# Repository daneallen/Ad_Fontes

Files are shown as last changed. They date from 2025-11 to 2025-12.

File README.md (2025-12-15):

# Ad Fontes STEM Project 2025

A project intended to introduce students to electrical engineering, printed circuit
board (PCB) design, soldering and embedded microcontroller programming.

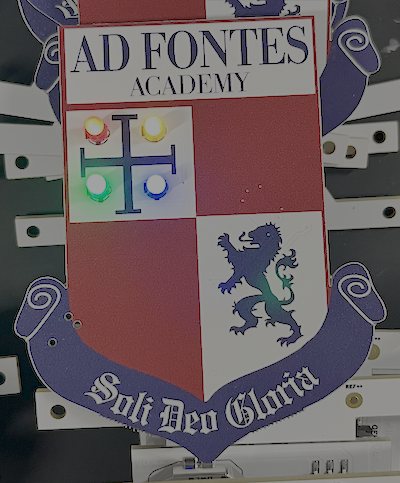
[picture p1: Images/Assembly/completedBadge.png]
Ad Fontes Completed Badge


# Day 1

Introduction to circuit design of the project. The entire design of the PCB was
completed using [KiCad](https://www.kicad.org/), a free and open sourced PCB software application.

The design of the circuit is built around the small and very capable [ATtiny1616](https://ww1.microchip.com/downloads/en/DeviceDoc/ATtiny1614-16-17-DataSheet-DS40002204A.pdf) microcontroller.

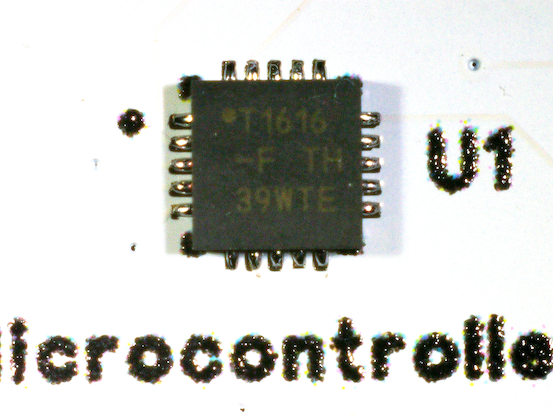
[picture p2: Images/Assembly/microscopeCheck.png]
Close up image of a soldered ATtiny1616


The entire schematic of the PCB is [here](/Documents/Schematic.pdf)

## Design Timeline

| Date | Notes |
| --- | --- |
| 8/23/25 | The PCB was first designed in KiCad |
| 8/28/25 | The first order of PCBs was placed. |
| 9/15/25 | The first of PCBs arrives. The design was sound, however the logo was too dark and there was improvements that could be made |
| 9/19/25 | Order #2 (v02) was placed to fix some of the identified issues |
| 10/6/25 | v02 badges arrive, Overall good, would benefit from a few additional things printed on the back of the board. |
| 10/19/25 | Order #3 (v03) was placed |
| 10/30/25 | v03 badge arrives. There is a problem with the back grounding plane... it was NOT filled in and so nothing works. |
| 11/10/25 | Order #4 (v04) was placed to finally fix all the things. |
| 11/20/25 | v04 arrives and is functional and ready for class. |

### Ideas for improvement

   - [x] lighten the colors for on the front of the badge for more contrast
   - [x] enlarge the test on the back of the badge... possibly expand/point out the different components
   - [x] remove the svg2mod on the front silkscreen
   - [x] better align the image on the front of the badge
   - [x] fix/address/remove the white parts near the mouse bites
   - [x] add a box and label for initials

# Day 2

On this day students will select the 4 LEDs that will be soldered onto their PCB.

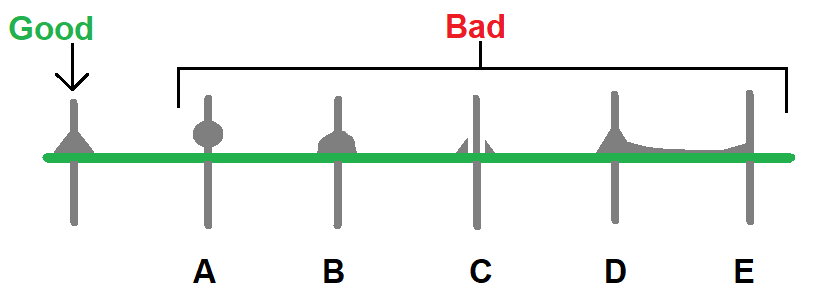
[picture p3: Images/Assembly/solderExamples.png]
Good & Bad solder examples


Basic Steps for Soldering:
   1. Introduce Heat
   2. Introduce Solder
   3. Remove the Solder
   4. Remove the Heat  

[YouTube Link for Soldering Example](https://www.youtube.com/watch?v=eHu_fGAyNY4)

# Day 3

Time to finish the PCB with some custom firmware. The ATtiny1616 utilizes the [Unified Program and Debug Interface (UPDI)]([https://learn.adafruit.com/adafruit-updi-friend/overview) protocol to program the microcontroller. Having the [Adafruit UPDI Friend Programmer](https://www.adafruit.com/product/5879) is quite helpful, especially when using it with the Tag-Connect [TC2030-IDC-NL](https://www.tag-connect.com/product/tc2030-idc-nl) 6-pin plug-of-nails connector tool.

## Programming the Badge

Programming the board is accomplished by using the interactive [programming script](/Arduino/Programming/programming.sh).

Available options are for the board to boot up into one of the following options:
1. Steady On all LEDs
2. Twinkle Effect
3. Chase Effect
4. Breathing Effect

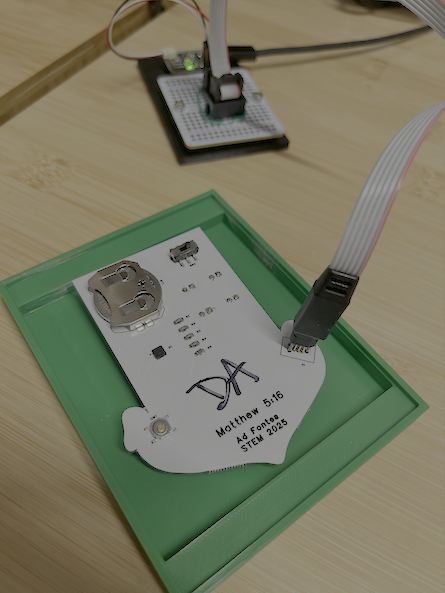
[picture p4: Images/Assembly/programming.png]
Programming the board


## Source Code

[Source Code](/Arduino/adFontes) for the board.

## Behind the Scenes

You will notice that there numerous components already assembled on the board prior to the 4 LEDs. Those components were assembled
in the following manner.

1. Setup the PCB in a jig to apply the solder paste.
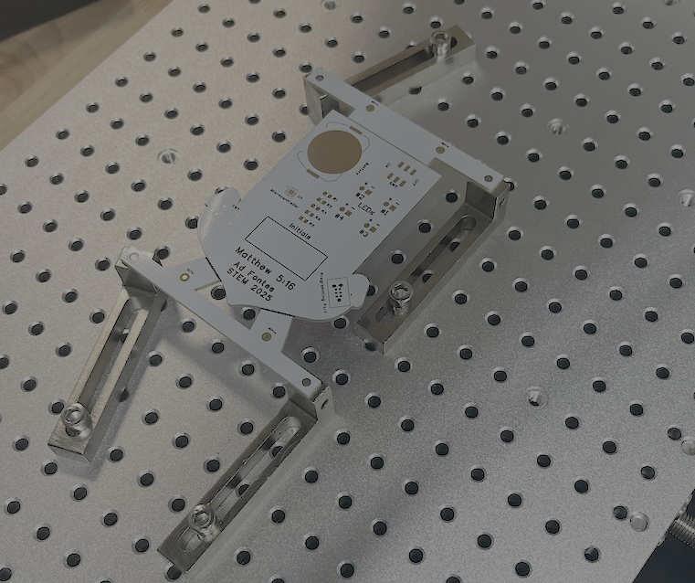
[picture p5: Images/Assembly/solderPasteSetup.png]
Solder Paste Setup


2. Apply the solder paste to the PCB.
Applying the Solder Paste

3. Setup the Pick and Place Machine and have it place all the small components to the board.
[Watch the PnP magic](/Images/Assembly/PnP.mp4)

4. Add the larger components by hand.
<br>Hand Placement of larger components

5. Put the board in the oven.
Placing the boards in the oven

6. Wait about 6 minutes for a freshly cooked badge to come out completed on the other side.
[Cooked badge](/Images/Assembly/ovenFinished.mov)

7. Pick your favorite 4 LED colors, solder them on and enjoy.

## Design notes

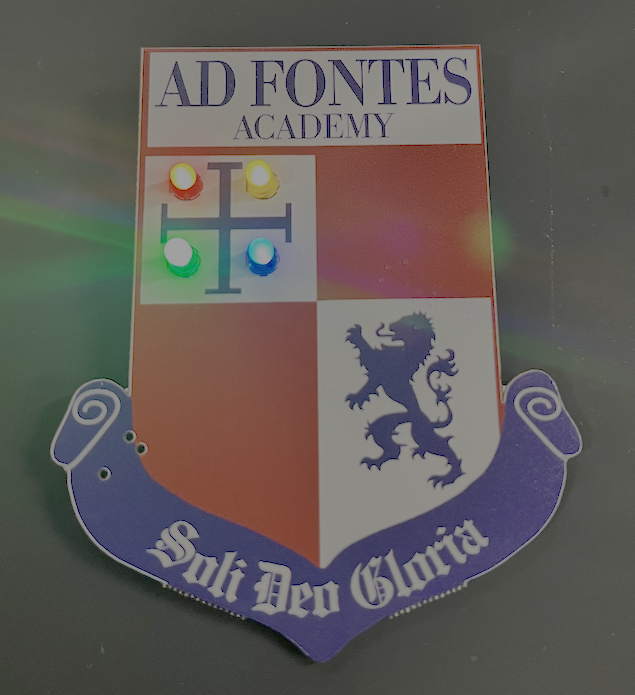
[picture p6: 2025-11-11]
Images/adFontes_front.png

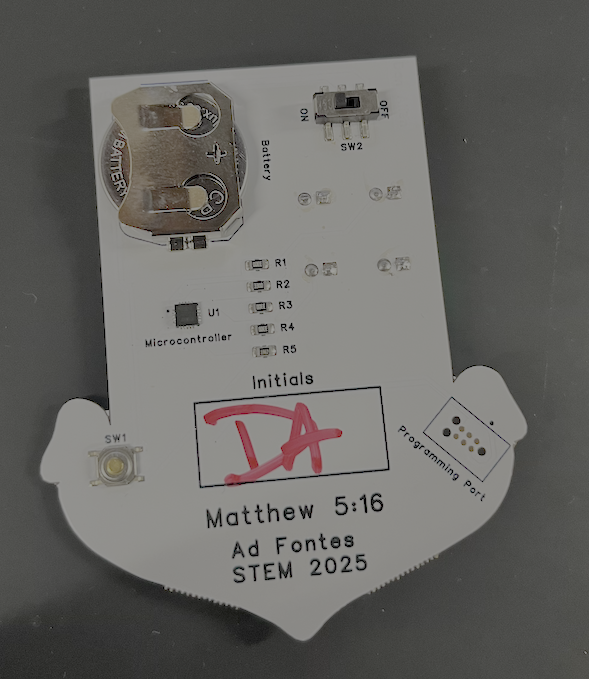
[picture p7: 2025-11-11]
Images/adFontes_back.png

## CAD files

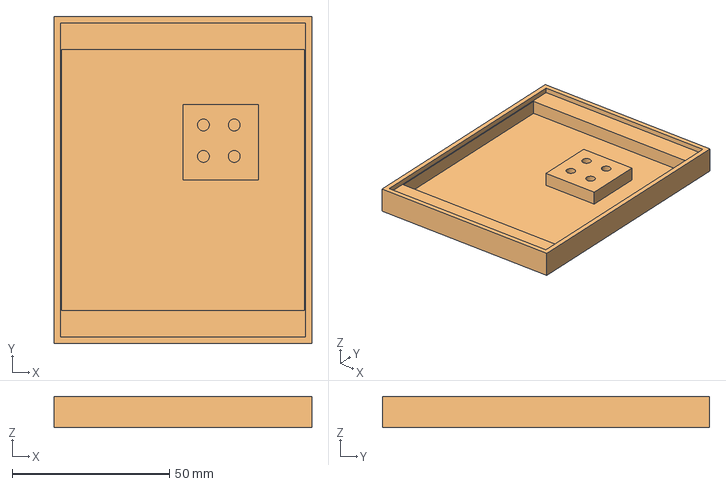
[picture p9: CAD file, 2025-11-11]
Assembly/sodlerJig.FCStd
82.0 x 104.0 x 10.0 mm
solderJig
solderJig (Meshed)

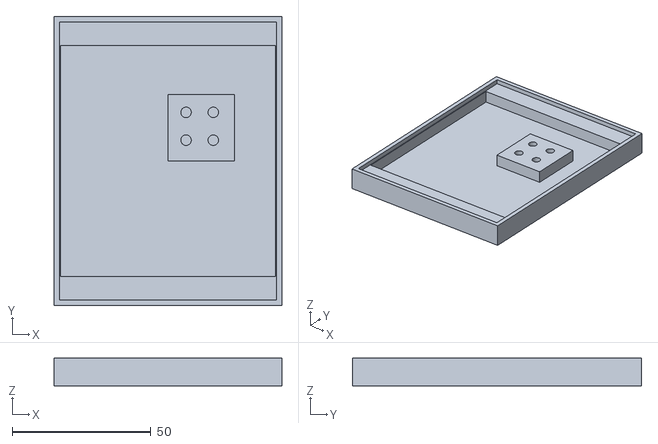
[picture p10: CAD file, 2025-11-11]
Assembly/solderJig (Meshed).stl
82.0 x 104.0 x 10.0

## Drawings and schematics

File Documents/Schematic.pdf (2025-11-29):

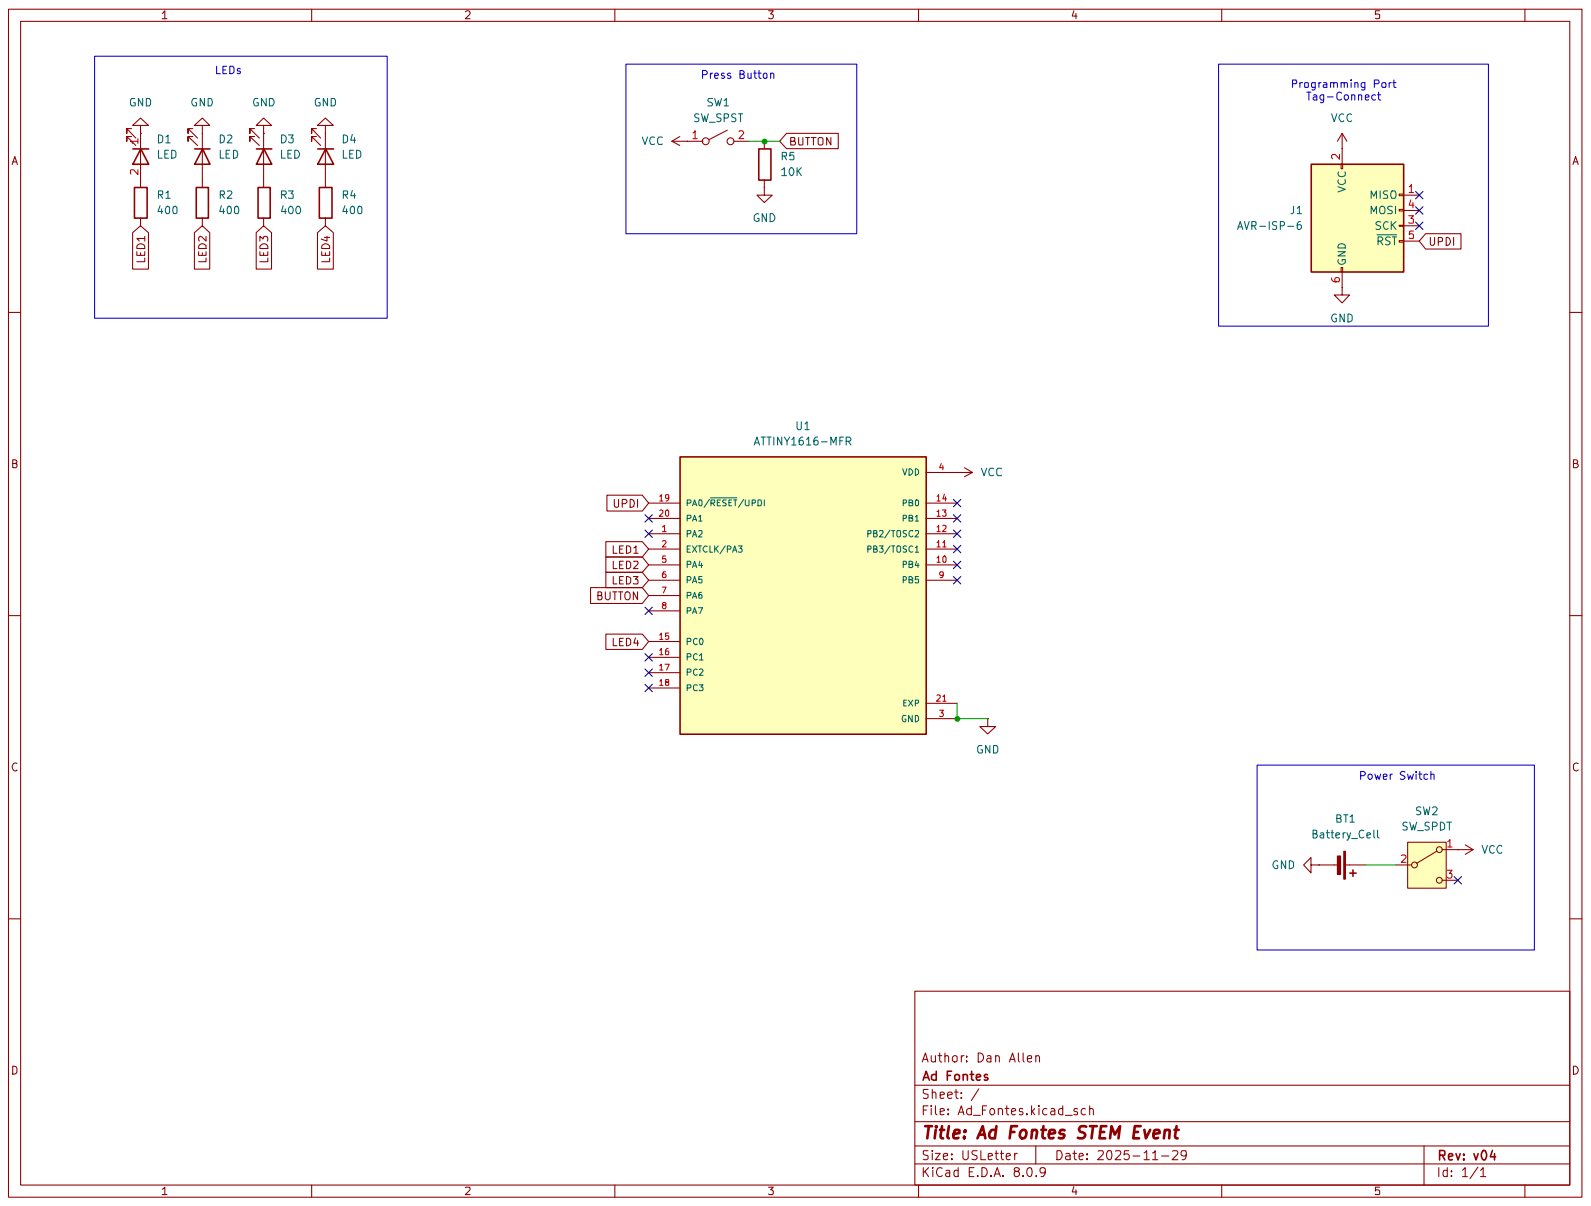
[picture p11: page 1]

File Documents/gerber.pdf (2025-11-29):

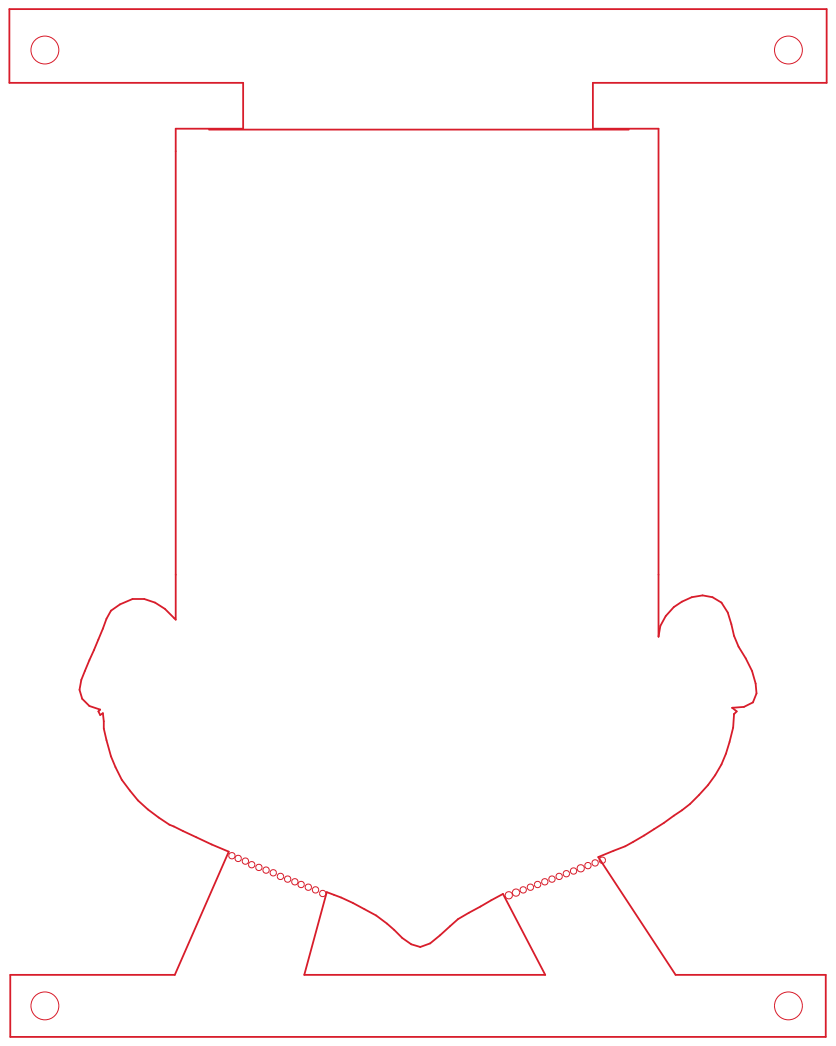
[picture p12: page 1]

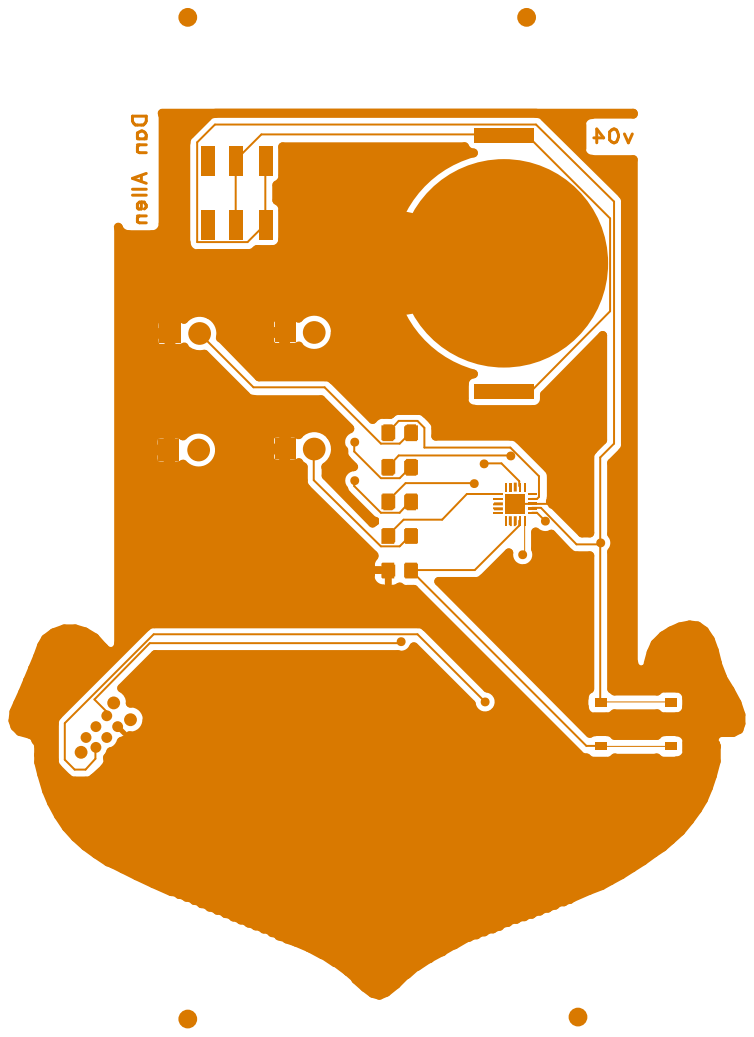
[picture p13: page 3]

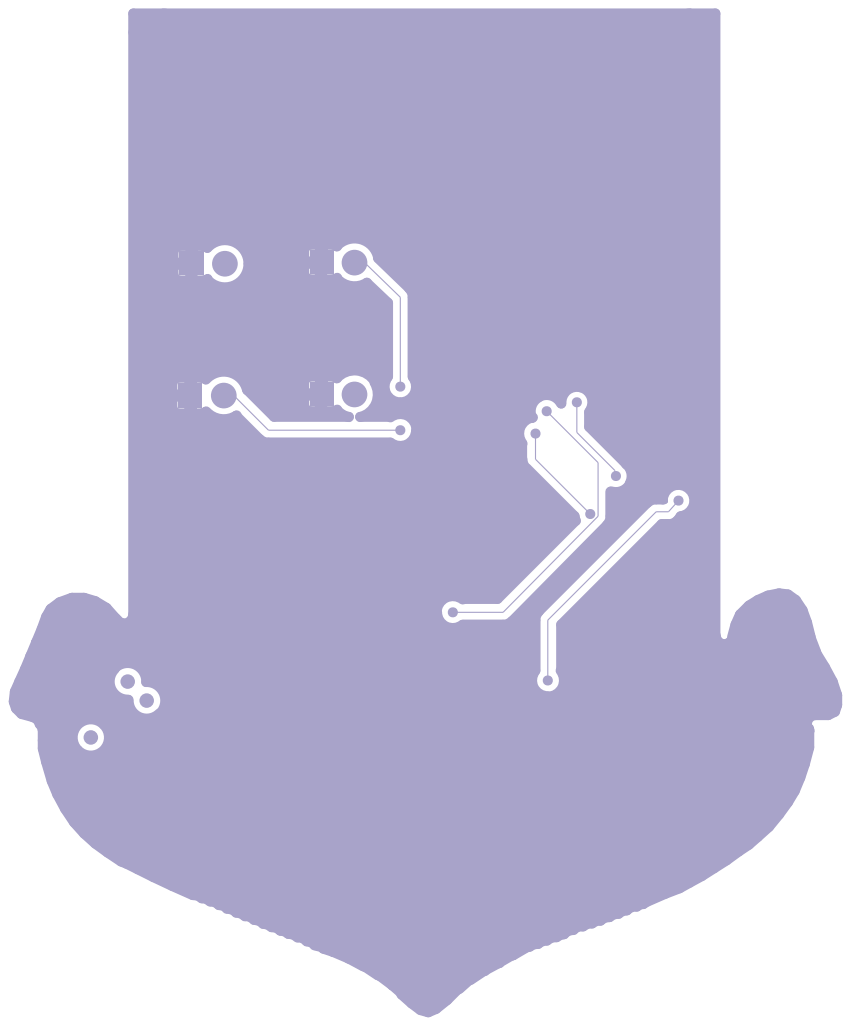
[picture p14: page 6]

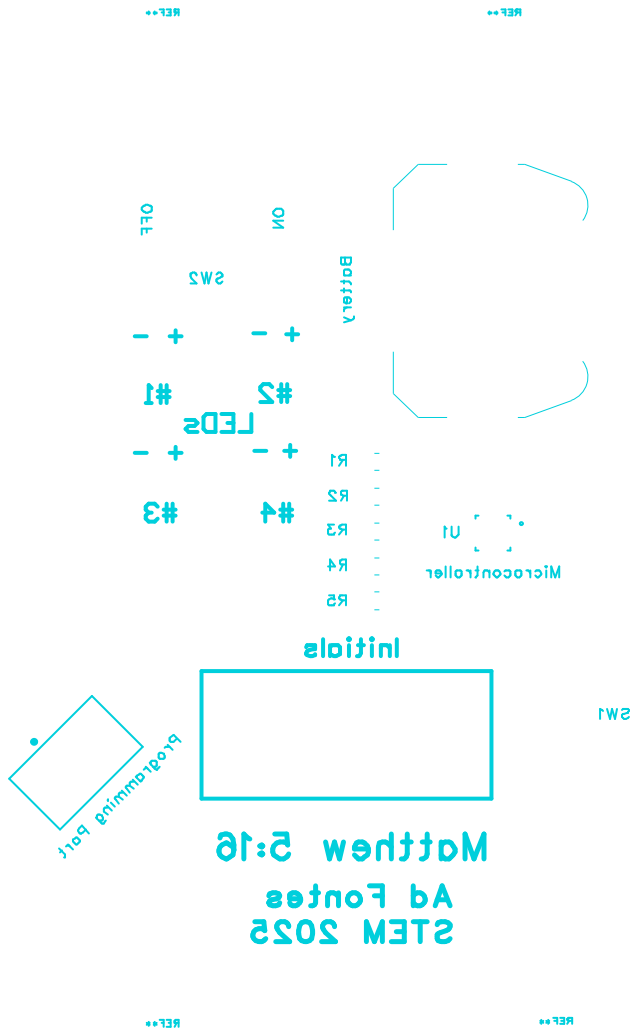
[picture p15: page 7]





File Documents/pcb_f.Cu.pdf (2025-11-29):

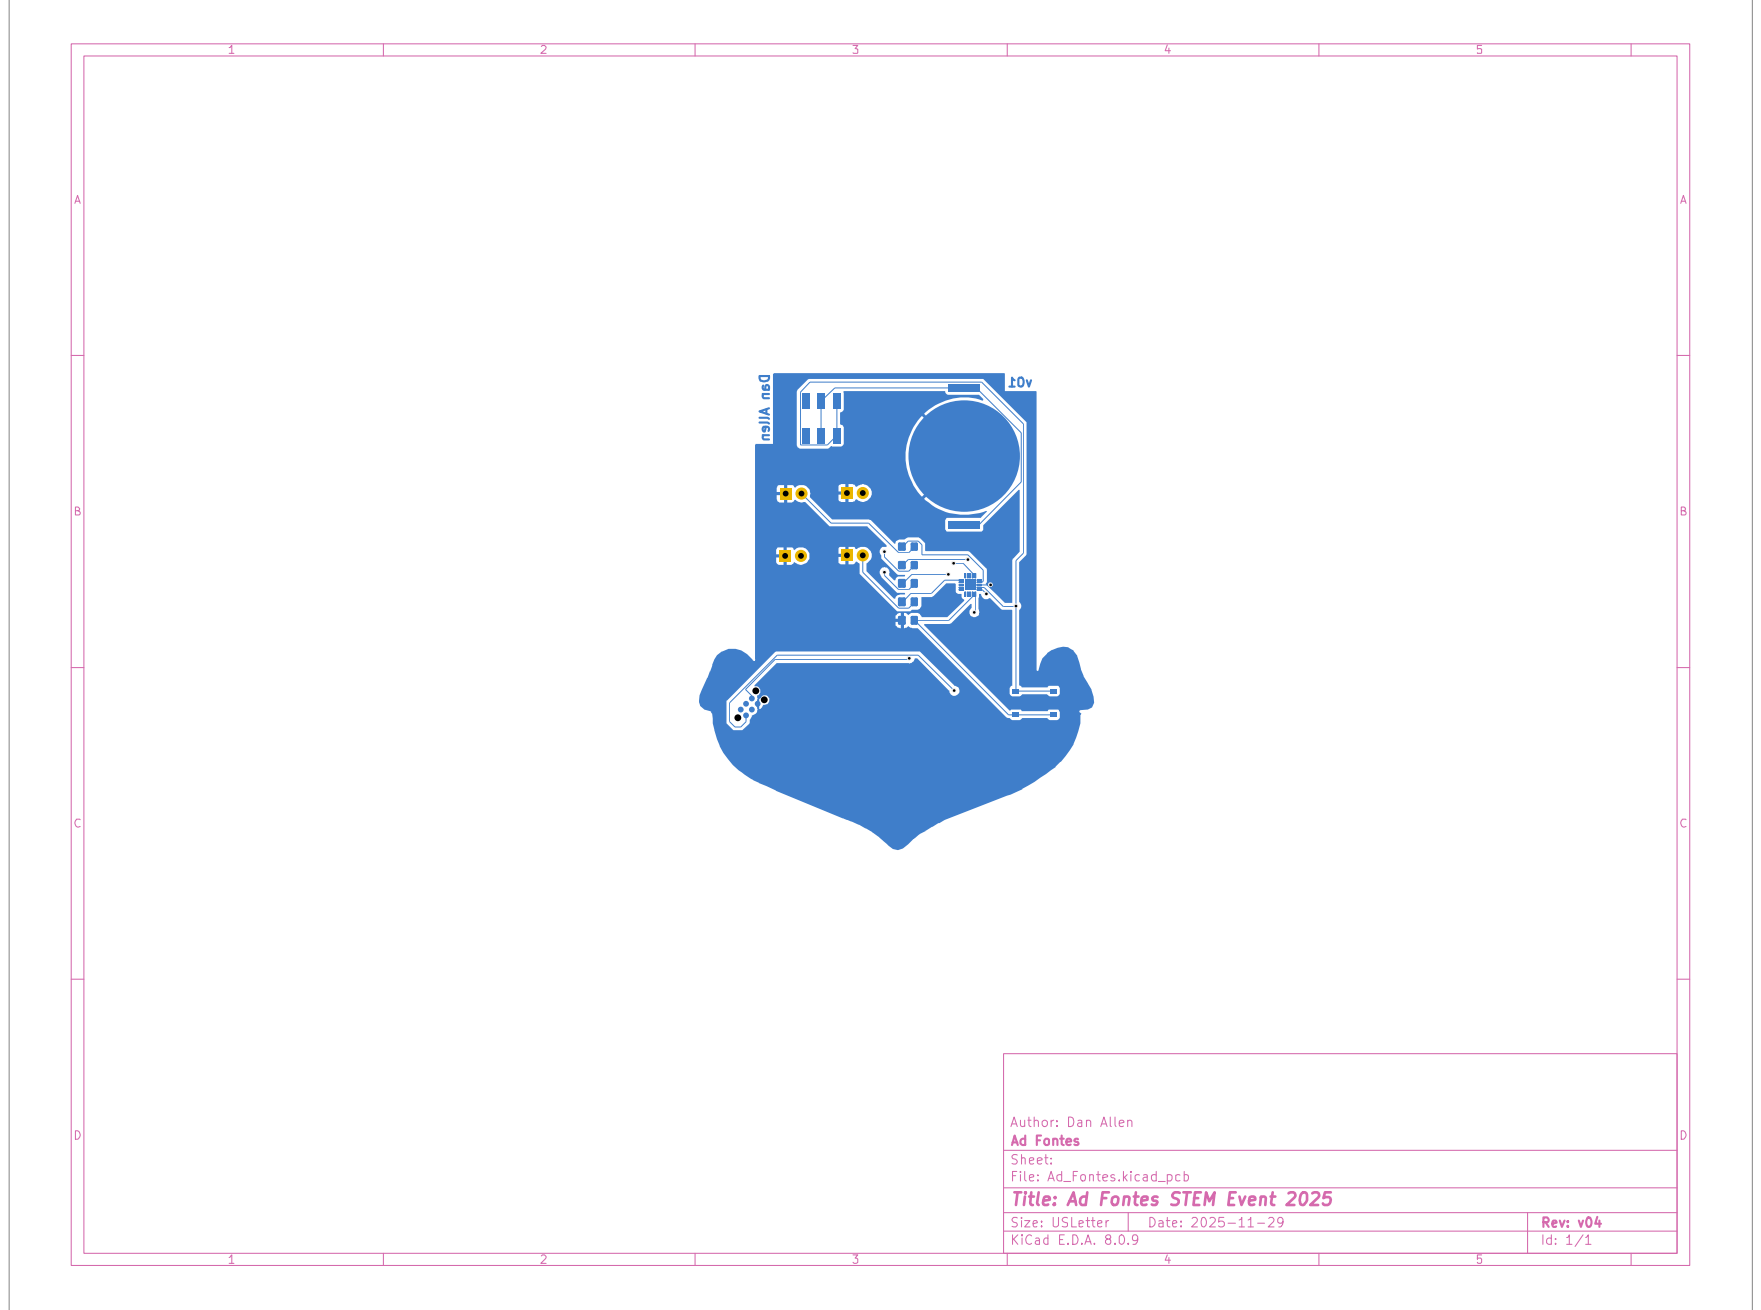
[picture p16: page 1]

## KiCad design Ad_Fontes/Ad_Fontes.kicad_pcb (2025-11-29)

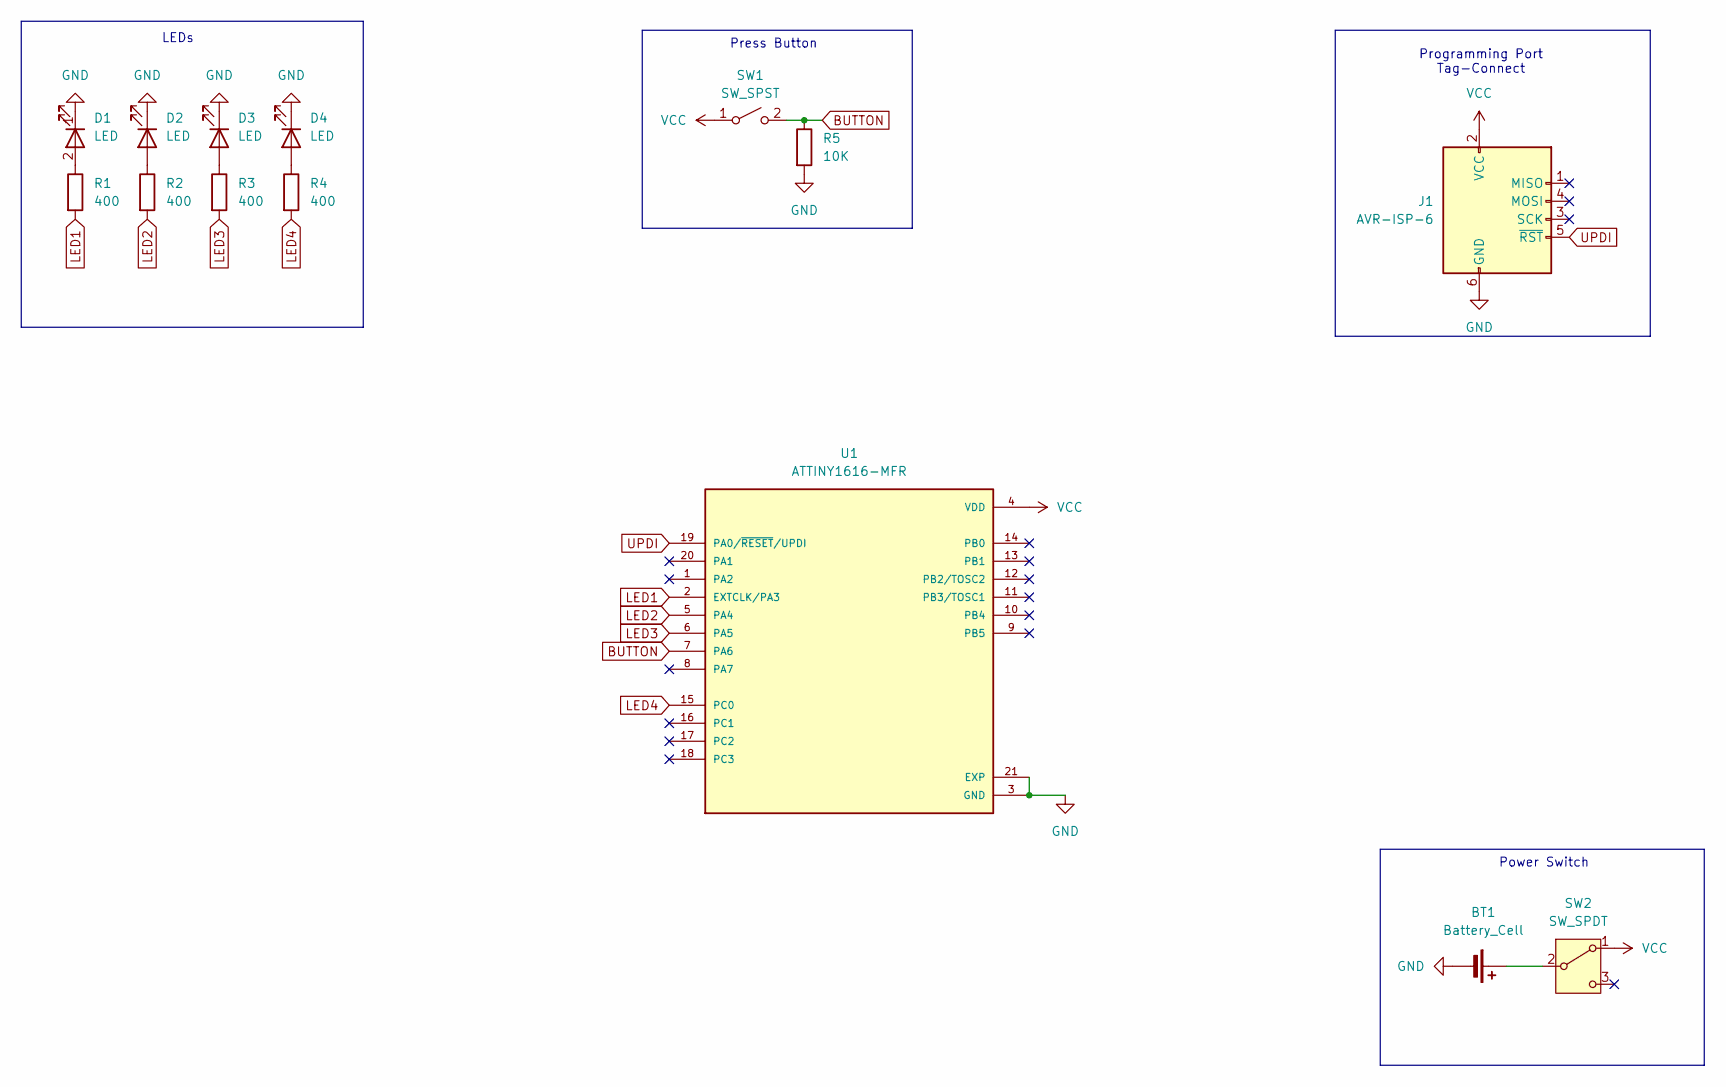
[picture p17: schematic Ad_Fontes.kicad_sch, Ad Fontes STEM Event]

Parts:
BT1: Battery_Cell; BatteryHolder_Keystone_3034_1x20mm
D1, D2, D3, D4: LED; LED_D3.0mm
J1: AVR-ISP-6; TAG_TC2030-IDC-NL
R1, R2, R3, R4: 400; R_0805_2012Metric_Pad1.20x1.40mm_HandSolder
R5: 10K; R_0805_2012Metric_Pad1.20x1.40mm_HandSolder
SW1: SW_SPST; PTS526
SW2: SW_SPDT; switch_JS202011SCQN
U1: ATTINY1616-MFR; QFN40P300X300X90-21N; PARTREV A; DigiKey_Part_Number ATTINY1616-MFRTR-ND

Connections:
BUTTON: R5.1, SW1.2 (B), U1.7 (PA6)
GND: BT1.2 (-), D1.1 (K), D2.1 (K), D3.1 (K), D4.1 (K), J1.6 (GND), R5.2, U1.3 (GND), U1.21 (EXP)
LED1: R1.2, U1.2 (EXTCLK/PA3)
LED2: R2.2, U1.5 (PA4)
LED3: R3.2, U1.6 (PA5)
LED4: R4.2, U1.15 (PC0)
unnamed: BT1.1 (+), SW2.2 (B)
unnamed: D1.2 (A), R1.1
unnamed: D2.2 (A), R2.1
unnamed: D3.2 (A), R3.1
unnamed: D4.2 (A), R4.1
UPDI: J1.5 (~RST), U1.19 (PA0/~RESET/UPDI)
VCC: J1.2 (VCC), SW1.1 (A), SW2.1 (A), U1.4 (VDD)

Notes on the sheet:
Press Button
LEDs
Programming Port Tag-Connect
Power Switch

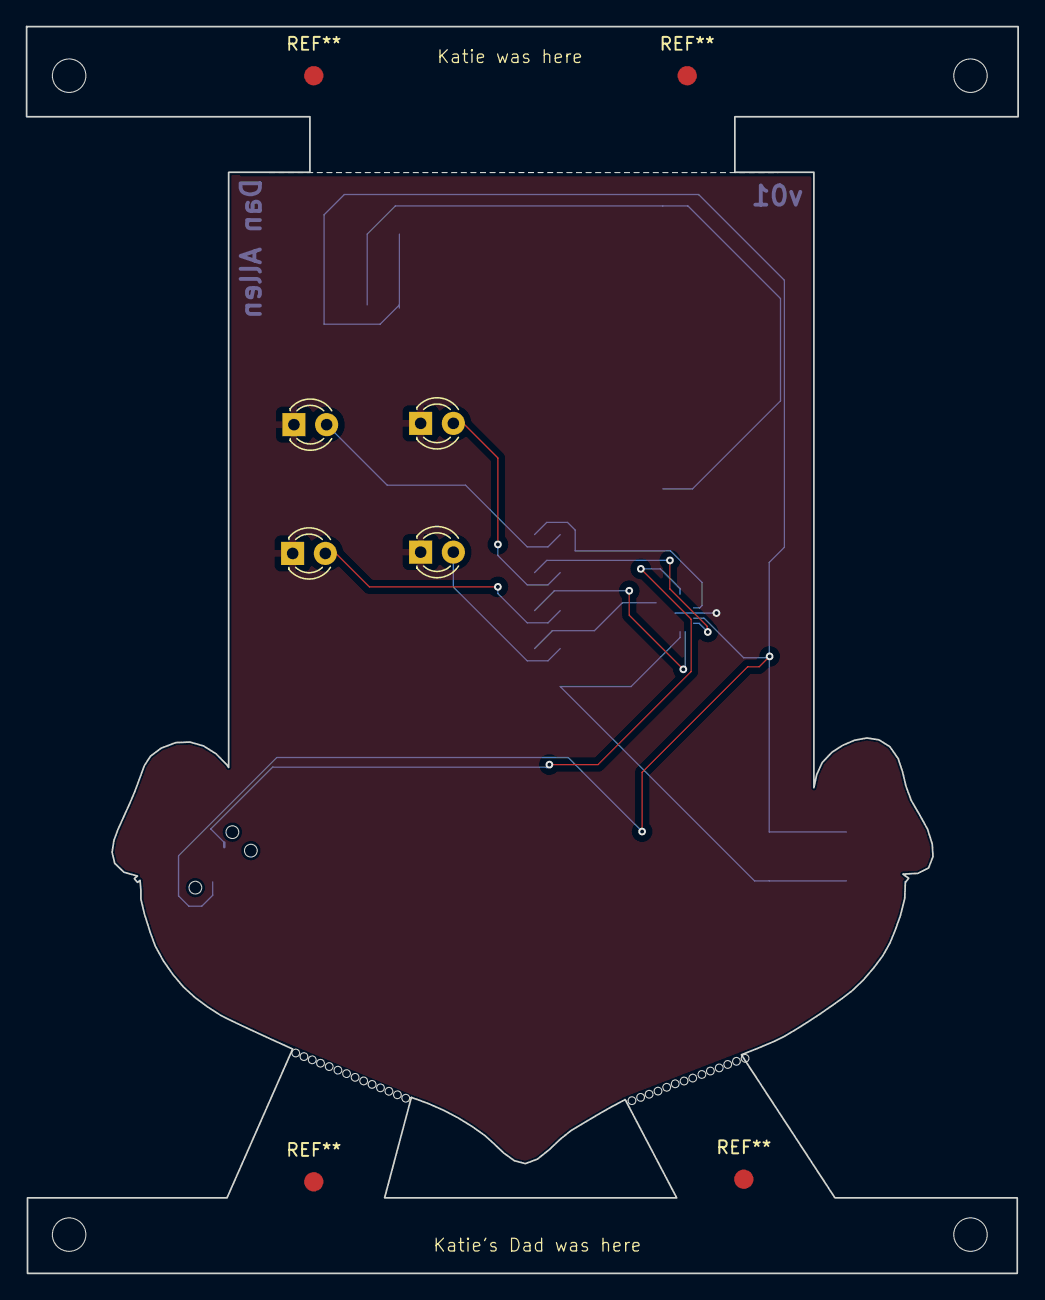
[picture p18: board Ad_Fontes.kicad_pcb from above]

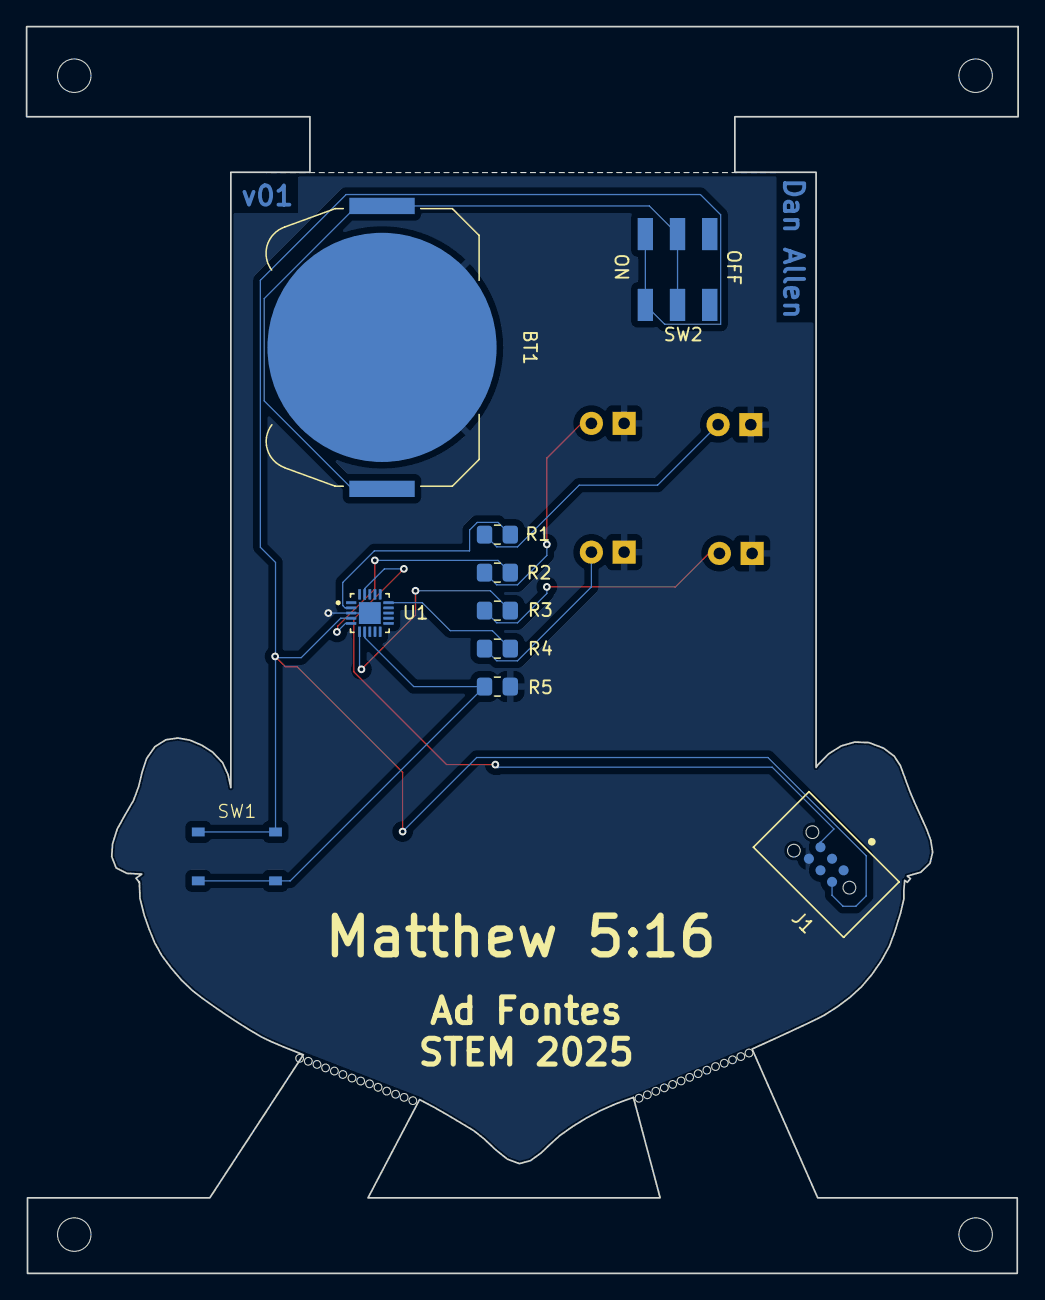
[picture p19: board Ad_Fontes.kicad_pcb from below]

Board: 2 copper layers, 77.0 x 96.8 mm, 15 parts (10 on the bottom side), 13 nets.

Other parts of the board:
svg2mod: G***; Ad Fontes Crest Logo

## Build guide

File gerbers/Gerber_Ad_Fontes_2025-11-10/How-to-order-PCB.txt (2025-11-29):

How to Order PCB

Please refer to:
https://prodocs.easyeda.com/en/pcb/order-order-pcb/index.html

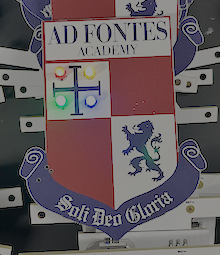
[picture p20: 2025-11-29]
Images/Assembly/completedFunctional.png

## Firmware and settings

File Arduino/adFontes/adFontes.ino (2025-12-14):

/* Ad Fontes STEM Badge 2025
 * 
 * author: @cybertestpilot
 * 
 */

#include <SoftwareTimer.h>

// The definitions of the pins mapped to the MCU
#define LED1 PIN_PA3
#define LED2 PIN_PA4
#define LED3 PIN_PA5
#define LED4 PIN_PC0
#define BUTTON A6


int led_array[4] = {LED1, LED2, LED3, LED4};
int led_array_index = 0;

int buttonState;            // the current reading from the input pin
int lastButtonState = LOW;  // the previous reading from the input pin

unsigned long lastDebounceTime = 0;  // the last time the output pin was toggled
unsigned long debounceDelay = 50;

// The initial value the board is set to for the purposes of the the LED initial state
int LED_STATE = 9;

int delay_value = 0;

// The delay value being used to set the twinkle effect of the random blinking
bool doTwinkle = false;
bool doDelay = false; 
unsigned long delayStart = 0;
unsigned long delayLenFast = 100;

void twinkleEffect();
SoftwareTimer twinkleTimer(100, &twinkleEffect);

void chaseEffect();
SoftwareTimer chaseTimer(200, &chaseEffect);
bool doChase = false;
int chaseIndex = 0;
int led_chase_array[4] = {LED1, LED2, LED4, LED3};

void breatheEffect();
SoftwareTimer breathTimer(15, &breatheEffect);
bool doBreathe = false;
int breathValue = 1;
int breathDir = 1;


void setup() {
  
  // put your setup code here, to run once:
  pinMode(LED1, OUTPUT);
  pinMode(LED2, OUTPUT);
  pinMode(LED3, OUTPUT);
  pinMode(LED4, OUTPUT);
  
  pinMode(BUTTON, INPUT);  
}

void twinkleEffect(){
  if(doTwinkle == true){
    for(int i=0; i<4; i++){
      analogWrite(led_array[i], random(1,255));
    }
  }
}

void chaseEffect(){
  if(doChase == true){
    for(int i=0; i<4; i++){
      if(i == chaseIndex){
        digitalWrite(led_chase_array[i], HIGH);
      }else{
        digitalWrite(led_chase_array[i], LOW);
      }
    }
    chaseIndex += 1;
    if(chaseIndex >= 4){
      chaseIndex = 0;
    }
  }
}

void breatheEffect(){
  if(doBreathe == true){
    for(int i=0; i<4; i++){
      analogWrite(led_array[i], breathValue);
    }
    breathValue += 1*breathDir;

    if(breathValue >= 250){
      breathDir = -1;
    }
    if(breathValue <= 10){
      breathDir = 1;
    }
  }
}


void loop() {
  // put your main code here, to run repeatedly:
  
  int reading = digitalRead(BUTTON);  // Read the value/state of the Button pin to see if it's been pressed

  // If the switch changed, due to noise or pressing:
  if (reading != lastButtonState) {
    lastDebounceTime = millis();  // reset the debouncing timer
  }

  if ((millis() - lastDebounceTime) > debounceDelay) {
    // whatever the reading is at, it's been there for longer than the debounce
    // delay, so take it as the actual current state:

    // if the button state has changed:
    if (reading != buttonState) {
      buttonState = reading;      

      // only toggle the LED if the new button state is HIGH
      if (buttonState == HIGH) {
        

        LED_STATE += 1;

        if(LED_STATE >= 10){
          LED_STATE = 0;
        }

        delay_value += 30;
        if(delay_value >= 255){
          delay_value = 1;
        }        
      }
    }
  }

  switch (LED_STATE) {
    case 0:
      doBreathe = false;
      digitalWrite(LED1, HIGH);
      digitalWrite(LED2, HIGH);
      digitalWrite(LED3, HIGH);
      digitalWrite(LED4, HIGH);      
      break;
    case 1:
      digitalWrite(LED1, HIGH);
      digitalWrite(LED2, LOW);
      digitalWrite(LED3, LOW);
      digitalWrite(LED4, HIGH);
      break;
    case 2:
      digitalWrite(LED1, LOW);
      digitalWrite(LED2, HIGH);
      digitalWrite(LED3, HIGH);
      digitalWrite(LED4, LOW);
      break;
    case 3:
      digitalWrite(LED1, HIGH);
      digitalWrite(LED2, LOW);
      digitalWrite(LED3, LOW);
      digitalWrite(LED4, LOW);
      break;
    case 4:
      digitalWrite(LED1, LOW);
      digitalWrite(LED2, HIGH);
      digitalWrite(LED3, LOW);
      digitalWrite(LED4, LOW);
      break;
    case 5:
      digitalWrite(LED1, LOW);
      digitalWrite(LED2, LOW);
      digitalWrite(LED3, HIGH);
      digitalWrite(LED4, LOW);
      break;
    case 6:
      digitalWrite(LED1, LOW);
      digitalWrite(LED2, LOW);
      digitalWrite(LED3, LOW);
      digitalWrite(LED4, HIGH);
      break;
    case 7: //twinkle effect
      doTwinkle = true;
      break;
    case 8: //chase effect
      doTwinkle = false;
      doChase = true;
      break;
    case 9: //breath effect
      doChase = false;
      doBreathe = true;
    default:
      break;
          
  }

  // save the reading. Next time through the loop, it'll be the lastButtonState:
  lastButtonState = reading;

  twinkleTimer.tick();
  chaseTimer.tick();
  breathTimer.tick();
}
